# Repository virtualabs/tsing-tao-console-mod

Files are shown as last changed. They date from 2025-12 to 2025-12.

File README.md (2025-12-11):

# Tsing Tao v1 - a cheap ESP32 mod for a cheap handheld

Tsing Tao is a set of three tiny printed circuit boards that can turn any cheap
Chinese handheld gaming console (sold as Game Boy like console with 400+ NES
games) into a full-featured retro emulator able to run GameBoy, Game Gear, NES,
and Master System ROMs.

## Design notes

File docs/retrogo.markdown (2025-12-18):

---
layout: default
title: Flashing RetroGo
nav_order: 4
---

Flashing Retro-Go
=================

Once the mod installed in the handeld console, it is time to flash the ESP32 system
with a compatible Retro-Go version that has been specifically developed for this mod.
Retro-Go is a wonderful ESP32 retro-gaming platform using various emulators to run
old games on emulated consoles. It is easy to deploy and the [project website](https://github.com/ducalex/retro-go)
does explain how to manage games on the device's SD card and much more. 

Download our custom Retro-Go image
----------------------------------

We provide a prebuilt image for this TsingTao mod that can be downloaded from [our release page](https://github.com/virtualabs/retro-go/releases/download/tsingtao-v1.0/tsingtao-retrogo-v1.img).
This image has been specifically built for this mod and features some hardcoded configuration
and custom drivers to correctly interface with the console screen and our dedicated daughter boards.

You can also follow [the build instructions](https://github.com/virtualabs/retro-go/blob/master/BUILDING.md)
to compile it from source, and flash the generated image into the mod system.

Flash your ESP32
----------------

*Important: do not insert any micro SD card in the console's SD card holder !*

First, you need to install `esptool` on your system, as it is required to successfully flash
the TsingTao Retro-Go image. It should be available in most Linux distributions as a standard
package, if not you can install it by following [Espressif's setup guide](https://docs.espressif.com/projects/esptool/en/latest/esp32/).

Then, connect your modded console to your computer using a USB cable. Make sure the console is powered
on (power switch facing `ON`), and issue the following command (replace ``tsingtao-retrogo-v*.img`` with the
filename of the image downloaded in the previous step):

```shell
$ esptool.py write_flash --flash_size detect 0x0 tsingtao-retrogo-v*.img
```

This operation can take minutes to complete. Once done, switch off the console.

First boot
----------

Format your micro SD card in FAT32 and insert it into the micro SD card holder. Then switch on
the console, it will fill the micro SD card with the required folders for ROMS and themes at
first boot.

Switch off the console again, eject the micro SD card and copy ROM files to the corresponding
folders and insert it again into the handeld. Switch it on, and you should see your games in
the list of games of the console they were designed to run on.

Enjoy !

Frequently Asked Questions
==========================

TsingTao is not detected when connected to my computer, did I do anything wrong ?
---------------------------------------------------------------------------------

First, make sure the USB cable used to connect the console to your computer is not a charge-only
USB cable. Then, check the power switch has correctly been placed when reassembling the console:
it could be misplaced and tit won't switch the console on. If any of this worked, check your
solder job and make sure the mod's `DM` and `DP` pads are correctly connected to the type A USB
plug.

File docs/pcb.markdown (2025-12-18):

---
layout: default
title: PCB Assembly
nav_order: 2
---

PCB Assembly
============

{:refdef: style="text-align: center;"}
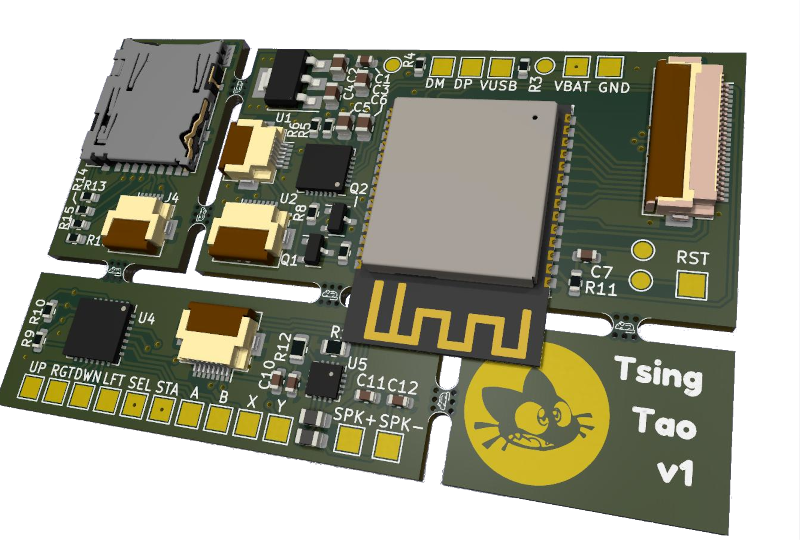
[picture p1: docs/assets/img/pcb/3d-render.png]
3D render of the mod's PCB

{: refdef}

Gerber export
-------------

This mod's PCB can be poroduced by many Chinese low-cost PCB manufacturers like [JLCPCB](https://jlcpcb.com) or
[PCBWay](https://pcbway.com) using [this Gerber file (ZIP)](https://raw.githubusercontent.com/virtualabs/tsing-tao-console-mod/refs/heads/main/gerber/tsing-tao-mod-v1.gerber.zip).

Bill of Materials
-----------------

| Designator |  Value |  Footprint | Description |  Quantity |
|---|---|---|---|---|
| R12 | 1 M | 0805 | Resistor 250mW | 1 |
| R4 | 47.5 k | 0603 | Resistor 250mW | 1 |
| R3 | 22.1k | 0603 | Resistor 250mW | 1 |
| R11, R6, R7, R8 | 10 k | 0603 | Resistor 250mW | 4 |
| R5 | 1 k | 0603 | Resistor 250mW | 1 |
| R13, R14, R15, R16 | 4.7 k | 0603 | Resistor 250mW | 4 |
| C9 | 10 uF | 0603 | Capacitor | 1 |
| C2, C3, C6 | 10 uF | 0805 | Capacitor | 3 |
| C5 | 1 uF | 0805 | Capacitor | 1 |
| C1, C7, C10 | 100 nF | 0603 | Capacitor | 2 |
| C11, C12 | 220 pF | 0603 | Capacitor | 2 |
| C4 | 100nF | 0805 | Capacitor | 1 |
| FB1, FB2 | - | 0805 | Ferrite bead | 2 |
| Q1, Q2 | MMS8050 | SOT-23-3 | NPN transistor | 2 |
| J1 | FH12-24S-0.5SH-1MP  | - | FPC connector, 24p, pitch 0.5mm| 1 |
| J2 | DM3AT-SF-PEJM5 | - | micro SD Card holder | 1 |
| J3, J4 | FH12-6S-0.5SH-1MP | - | FPC connector, 6p, pitch 0.5mm | 2 |
| J5, J6 | FH12-8S-0.5SH-1MP | - | FPC connector, 8p, pitch 0.5mm | 2 |
| U1 | AMS1117-3.3 | SOT-223-3 | LDO 3.3V 1A | 1 |
| U2 | CP2102N | QFN-28-1EP_5x5mm | USB-to-UART bridge | 1 |
| U3 | ESP32-S3-WROOM-1 | - | ESP32 S3, Espressif | 1 |
| U4 | MCP23017_ML | QFN-28-1EP_6x6mm | I2C GPIO expander, 16 IO | 1 |
| U5 | MAX98357A | TQFN-16-1EP_3x3mm| I2S Audio DAC + Amp. | 1 |

PCB soldering
-------------

*Note:* the pictures showed in this section have been taken during the soldering of the second
prototype PCB. This previous version did not have mousebites and each section had to be soldered
separately. The PCB version presented here does have mousebites and can be soldered in a single piece.

To solder this printed circuit board, use the classic procedure:
- apply solder paste using a stencil or by hand
- pick and place components manually (mind their orientation, especially for ICs)
- use a hot plate soldering device to heat up the PCB until the solder paste melt, make sure all components are soldered and remove from the hot plate.

{:refdef: style="text-align: center;"}
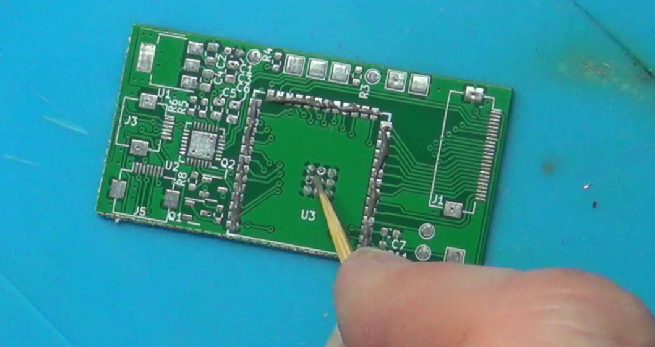
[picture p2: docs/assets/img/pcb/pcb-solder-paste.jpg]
Solder paste placed on pads

{: refdef}

{:refdef: style="text-align: center;"}
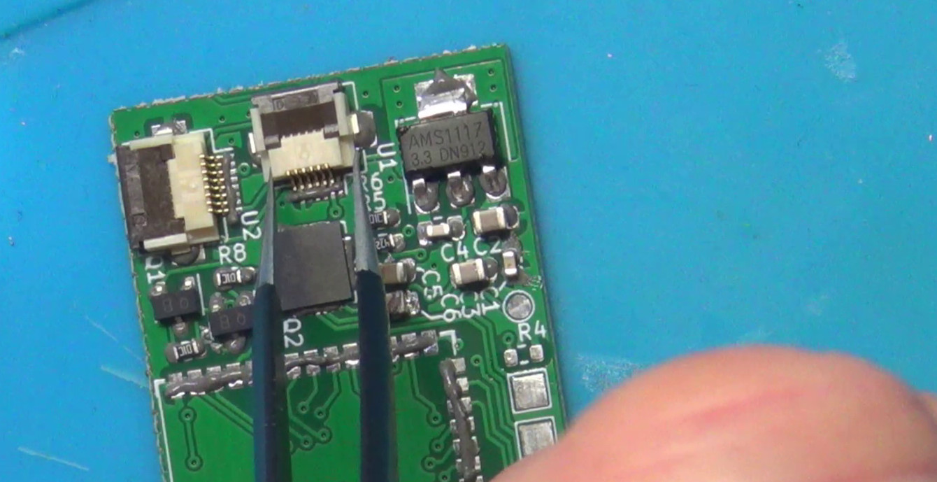
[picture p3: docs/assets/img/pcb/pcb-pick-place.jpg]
Placing components on PCB

{: refdef}

{:refdef: style="text-align: center;"}
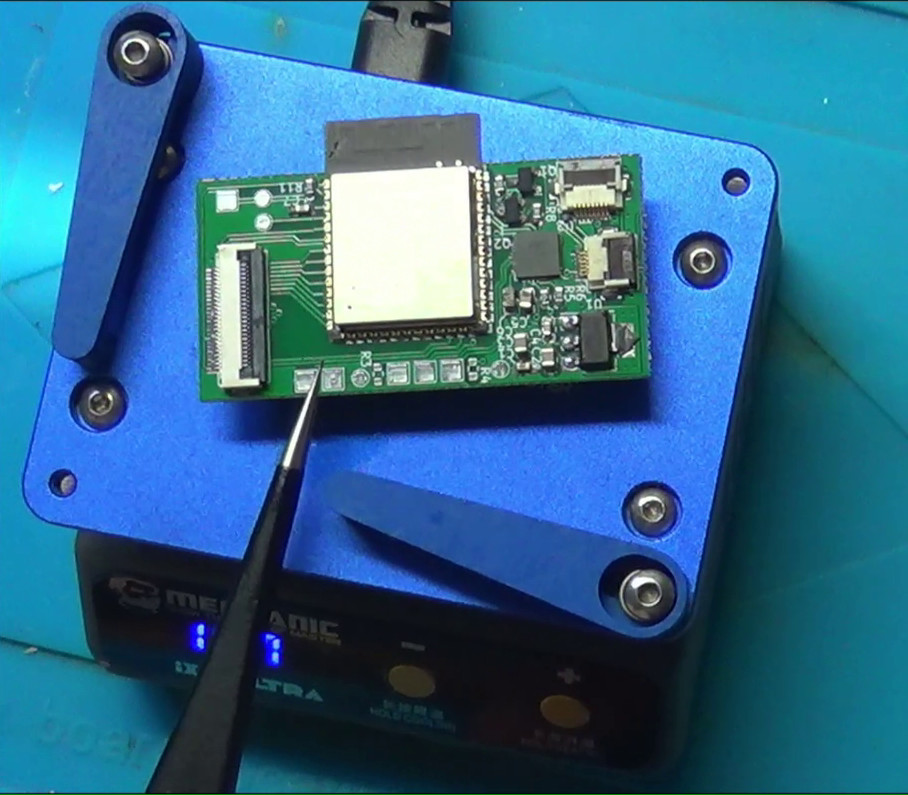
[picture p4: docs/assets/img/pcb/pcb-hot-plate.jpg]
Reflow with a Mechanic hotplate

{: refdef}

{:refdef: style="text-align: center;"}
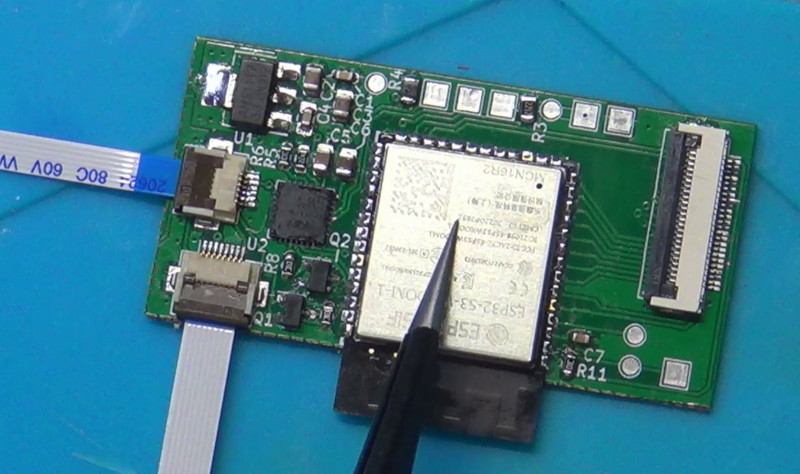
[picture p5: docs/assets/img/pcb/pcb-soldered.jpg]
Soldered PCB

{: refdef}

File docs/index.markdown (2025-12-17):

---
layout: default
nav_order: 1
---

Introducing TsingTao
====================

TsingTao is a custom mod for those cheap Chinese consoles you can find on the Internet,
like the one below:

{:refdef:  style="text-align: center;"}
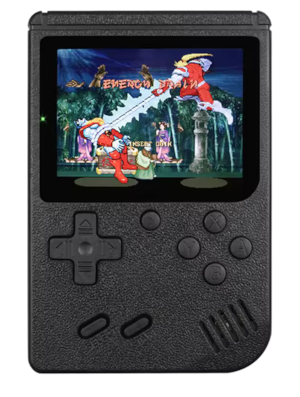
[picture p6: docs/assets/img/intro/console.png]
Cheap handeld console from AliExpress

{: refdef}

The goal of this mod is to reuse the following components of this console:
- console shell and lid
- 1020 mAh battery
- power and battery management circuit
- TFT screen
- speaker

This mod runs with a [Retro-Go](https://github.com/ducalex/retro-go) based firmware on a ESP32-based system and is able to
correctly emulate ROMS for the following consoles:
- Nintendo NES
- Nintendo GameBoy & GameBoy Color
- SEGA Game Gear
- SEGA Master System
- PC Engine
- Atari Lynx

Required hardware
-----------------

- 1 cheap Chinese handeld console, [like this one](https://fr.aliexpress.com/item/1005005986614521.html)
- 1 TsingTao mod kit (PCB + components)
- a soldering iron with enough solder (.5mm diameter recommended)
- desoldering wick
- soldering flux
- a pair of tweezers
- AWG30 monocore wire (or similar)
- .15mil enameled copper wire (very thin silicon-coated monocore wire could also work)
- tiny hot plate for PCB assembly, [like this one](https://fr.aliexpress.com/item/1005008702721210.html)
- a dremel equiped with a cutting disc, or equivalent

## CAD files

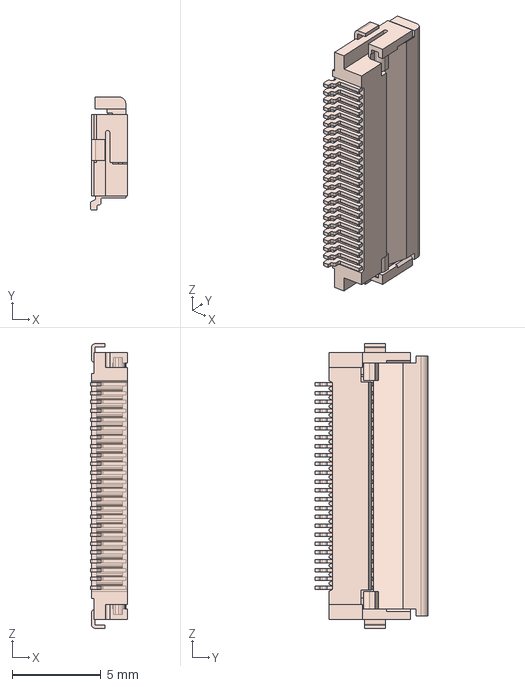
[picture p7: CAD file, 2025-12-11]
pcb/FH12-24S-0.5SH(55)--3DModel-STEP-1.STEP
2.10 x 6.40 x 16.1 mm

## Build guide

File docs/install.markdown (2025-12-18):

---
layout: default
title: Installation
nav_order: 3
---

Installation
============

This section details the installation of the *TsingTao* mod inside the console.

Disassembling the handeld
-------------------------

First, remove the console lid and battery located on the rear side of the device. Then remove the
six screws holding the the two halves of the console's main shell:

{:refdef: style="text-align: center;"}
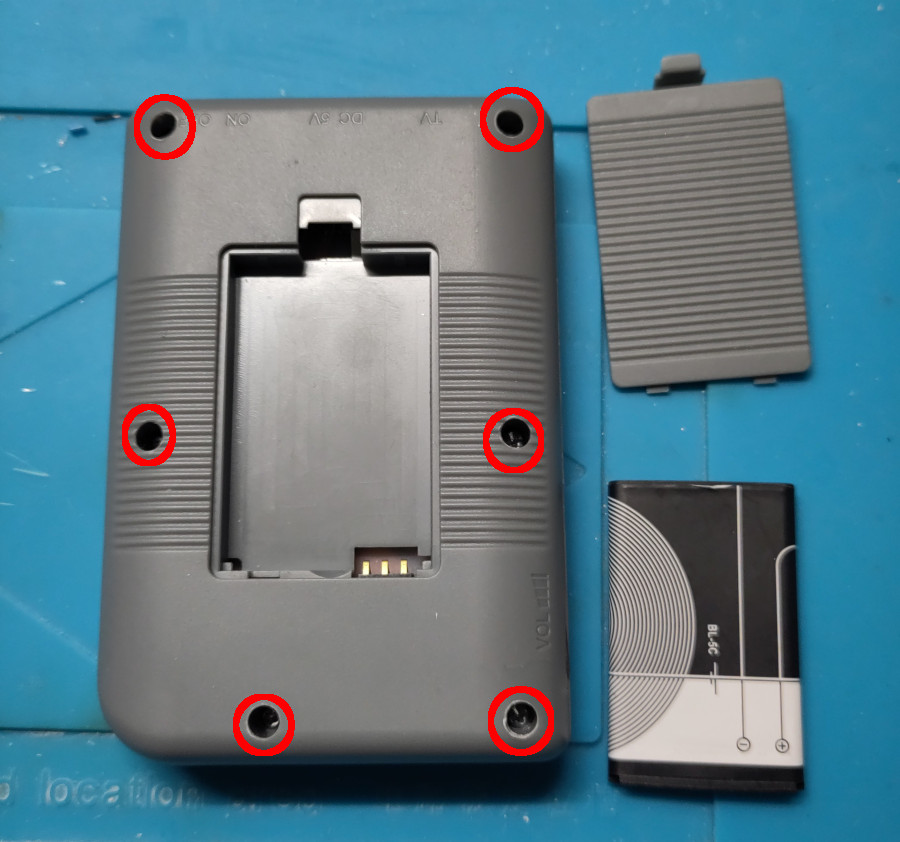
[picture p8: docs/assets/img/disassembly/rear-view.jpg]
Location of the six screws

{: refdef}

Once opened, extract the PCB from the device and put the two halves of the main shell aside.
This PCB should look like the one below (note that there are a lot of variants for these handeld
consoles, it is very likely that your PCB differs from the one showed here):

{:refdef: style="text-align: center;"}
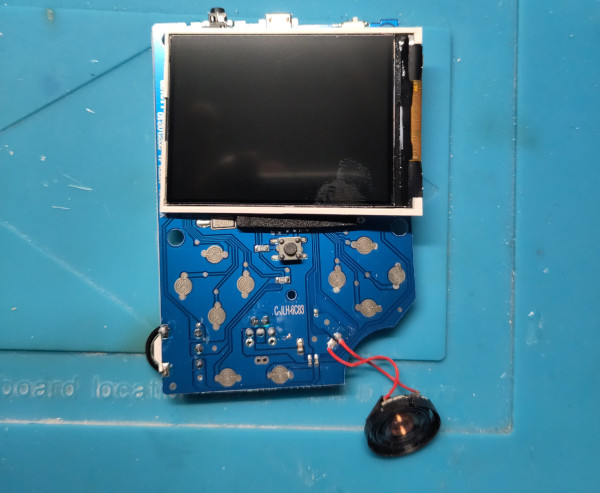
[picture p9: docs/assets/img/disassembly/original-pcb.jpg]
Original PCB extracted from handeld

{: refdef}

Disconnect the screen from the PCB: gently lift the socket's lip with a plastic tool (avoid using a blade
or a flat screwdriver as it may damage the screen's ribbon) and caregully remove the ribbon from the socket.
Keep this screen far from the workbench to avoid any scratch or damage (required in the final build).

Desolder the speaker using a soldering iron and a pair of tweezers. Keep it in a secure place to avoid any
damage, we will need it later.

Prepping the board
------------------

We need to get rid of the original ASIC and flash memory to make some space for our mod:
- desolder the main Flash chip by using a soldering iron or a hot plate
  (flash chip aspect may differ from the one showed below, depending on the version and variant)
- with a dremel, cut the PCB following the lines showed below

{:refdef: style="text-align: center;"}
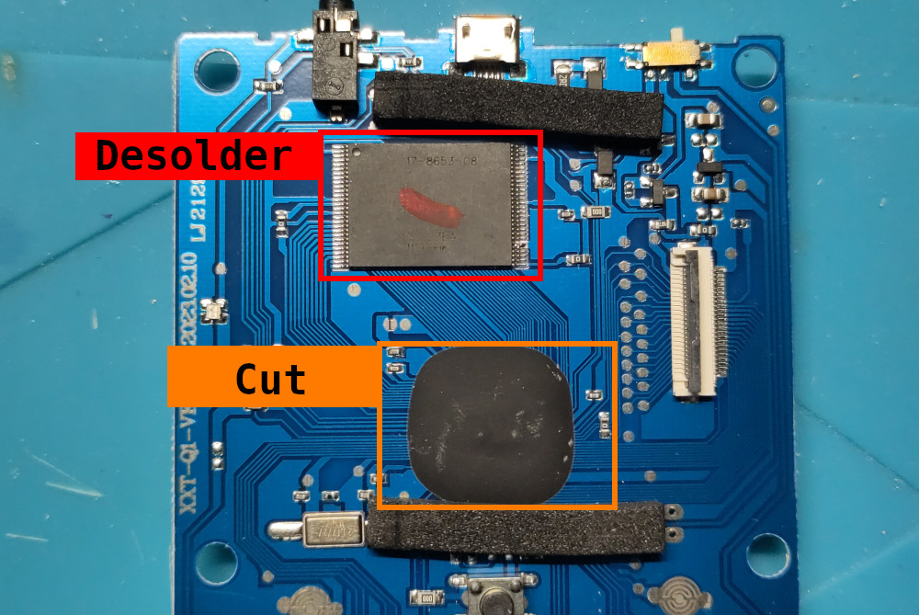
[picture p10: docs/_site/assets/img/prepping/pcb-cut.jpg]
Desolder main Flash and cut out ASIC

{: refdef}

Please desolder and cut wisely, avoid touching any other critical components like those related to power
supply, USB port or screen connector. Cut as close as possible from the ASIC (the big black epoxy blob)
and try to keep the reset button intact (the tactile switch placed just below the ASIC).

Installing the main PCB
-----------------------

Once the ASIC and Flash chip removed, place the main PCB of the *TsingTao* mod onto the original PCB in
a way the screen connector is placed close to its original location. Use some double-sided tape to stick
it to the original PCB before doing any soldering job.

{:refdef: style="text-align: center;"}
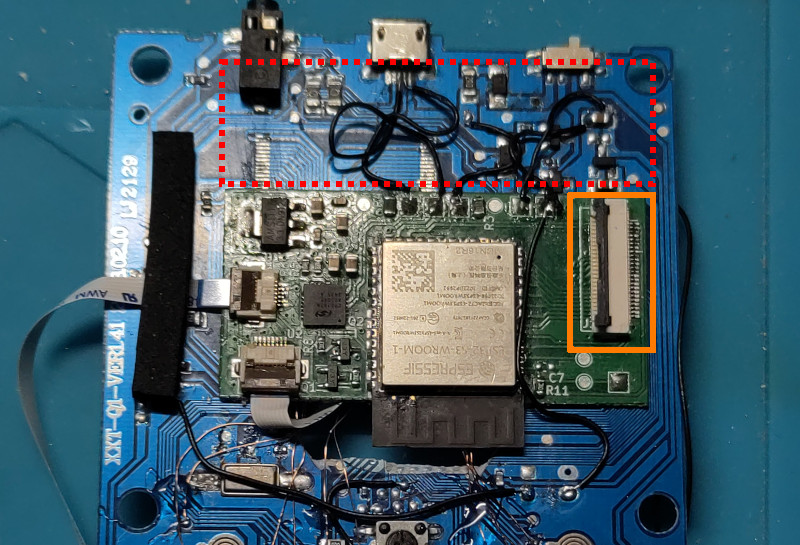
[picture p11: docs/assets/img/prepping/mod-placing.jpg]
Placing the mod onto the original PCB

{: refdef}

Avoid covering the area marked in red as it holds the power supply circuit and make sure the screen
connector aligns perfectly with the original screen connector location (marked in orange).

Soldering the main mod's PCB
----------------------------

Before soldering, make sure you have already identified the main power supply lines:
- `+5V` provided by the USB socket
- `Vbat` that corresponds to the battery voltage, usually wired to the device's power switch
- `Gnd` (basically tied to the original board's ground plane and USB socket's external case)

Cut the USB socket `D+` and `D-` tracks and solder two wires:
- one from the socket's `D+` pad to the mod's PCB `DP` pad
- one from the socket's `D-` pad to the mod's PCB `DM` pad

Then, solder the power supply wires:
- from the board's `+5V` taken from the USB socket to the mod's PCB `5V` pad
- from the board's `Vbat` power line to the mod's PCB `VBAT` pad
- from the board's `GND` to the mod's PCB `GND` pad

{:refdef: style="text-align: center;"}
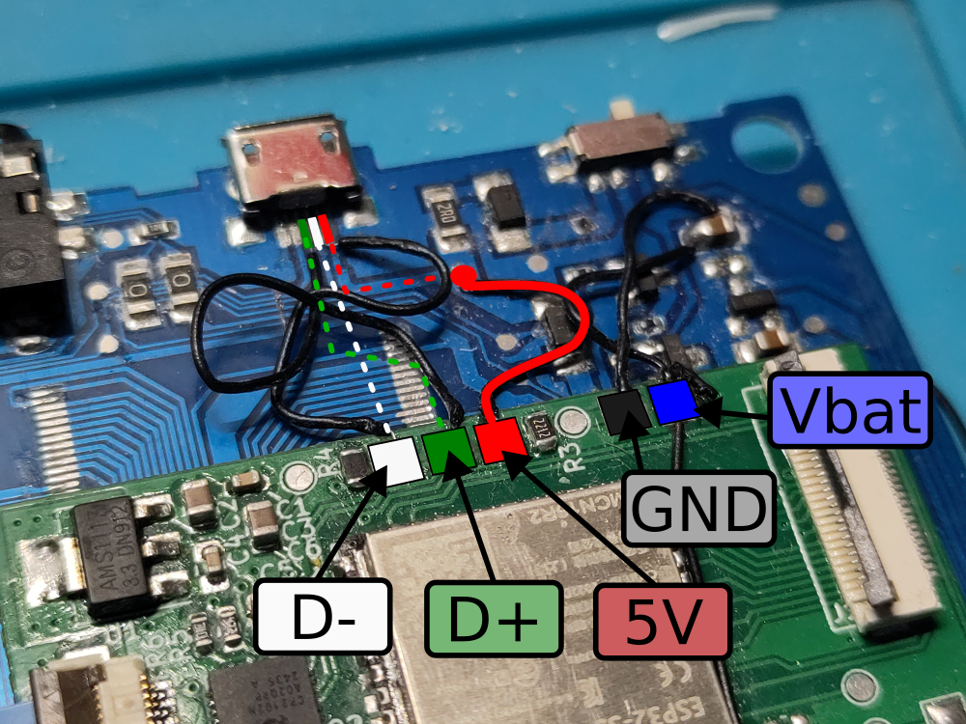
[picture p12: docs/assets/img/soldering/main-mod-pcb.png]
Main mod PCB soldering

{: refdef}

The mod's main PCB is now conencted to the device's USB port and power lines.
We can test it by connecting it to a host computer through a USB cable while
keeping its power switch set to *OFF*. A USB device should be shortly detected
and then disconnected as the ESP32 is keeping rebooting (since it has not already
been programmed).

Soldering the auxiliary PCB (handling buttons and sound)
--------------------------------------------------------

The mod's auxiliary PCB is in charge of probing the console's buttons and sending
audio to the external speaker. It should be placed on the back side of the handeld's
original PCB, placed under the USB connector. This auxialiary PCB is connected to
the mod's main PCB through a 8-pin flat ribbon.

We use small enameled wires to connect the buttons to this PCB, as shown below:

{:refdef: style="text-align: center;"}
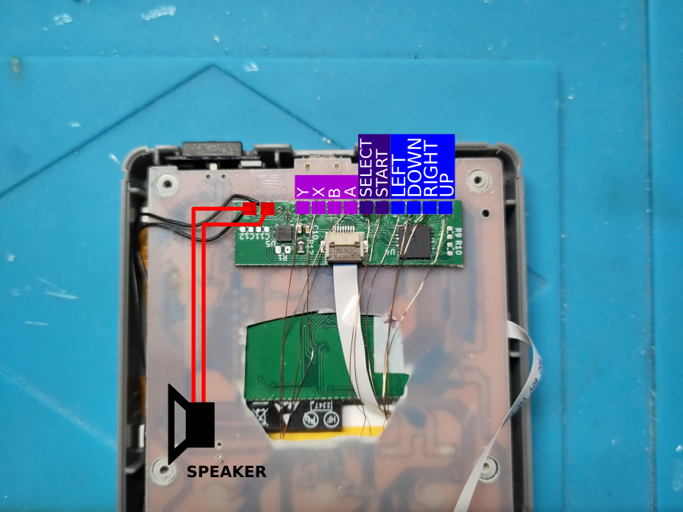
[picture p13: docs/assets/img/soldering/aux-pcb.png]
Aux mod PCB soldering

{: refdef}

{:refdef: style="text-align: center;"}
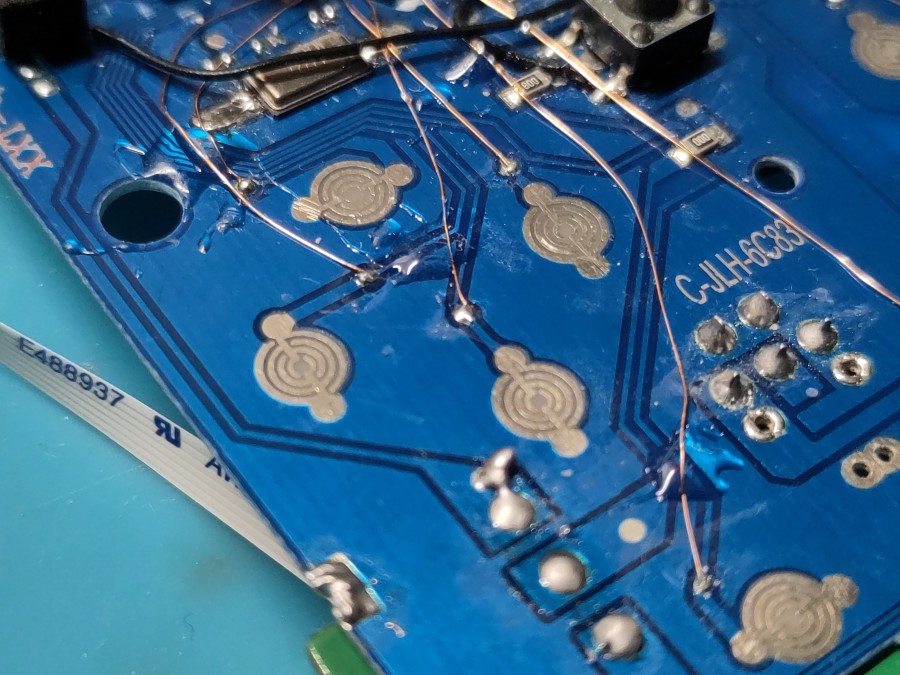
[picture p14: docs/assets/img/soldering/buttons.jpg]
Soldering buttons

{: refdef}

Installing the SD card holder
-----------------------------

Place and tape the SD card PCB module at the bottom of the original PCB's back side,
as showed below:

{:refdef: style="text-align: center;"}
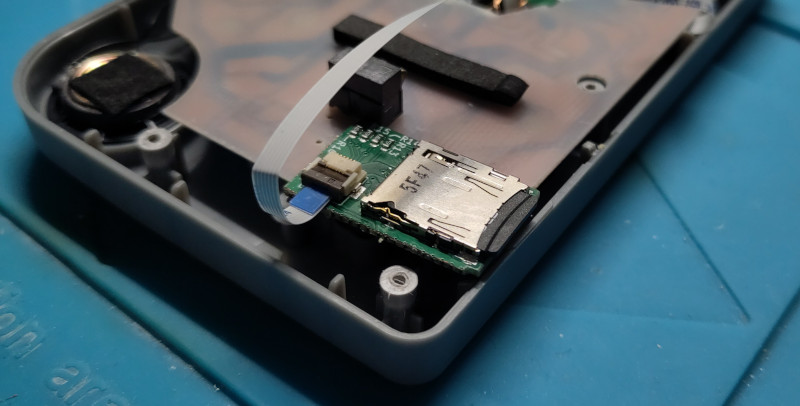
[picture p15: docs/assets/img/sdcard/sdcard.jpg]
SD card module taped

{: refdef}

Once placed and secured, connect it to the main mod's PCB using a 6-pin flex
ribbon. Cut the main shell's bottom half to make some room for the SD card
and allow easy access from the outside. The picture below shows how it was
done for our first prototype:

{:refdef: style="text-align: center;"}
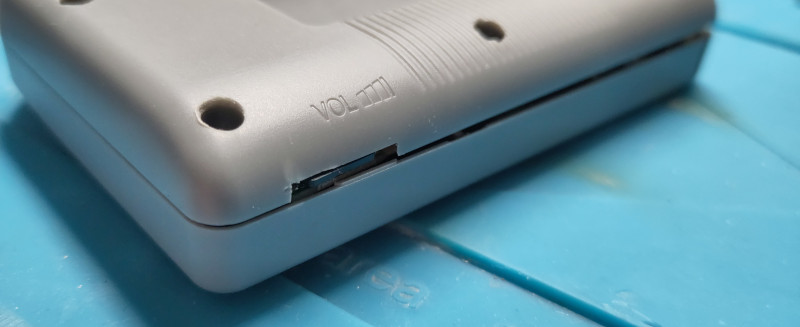
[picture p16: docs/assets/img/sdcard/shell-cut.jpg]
Cut shell

{: refdef}

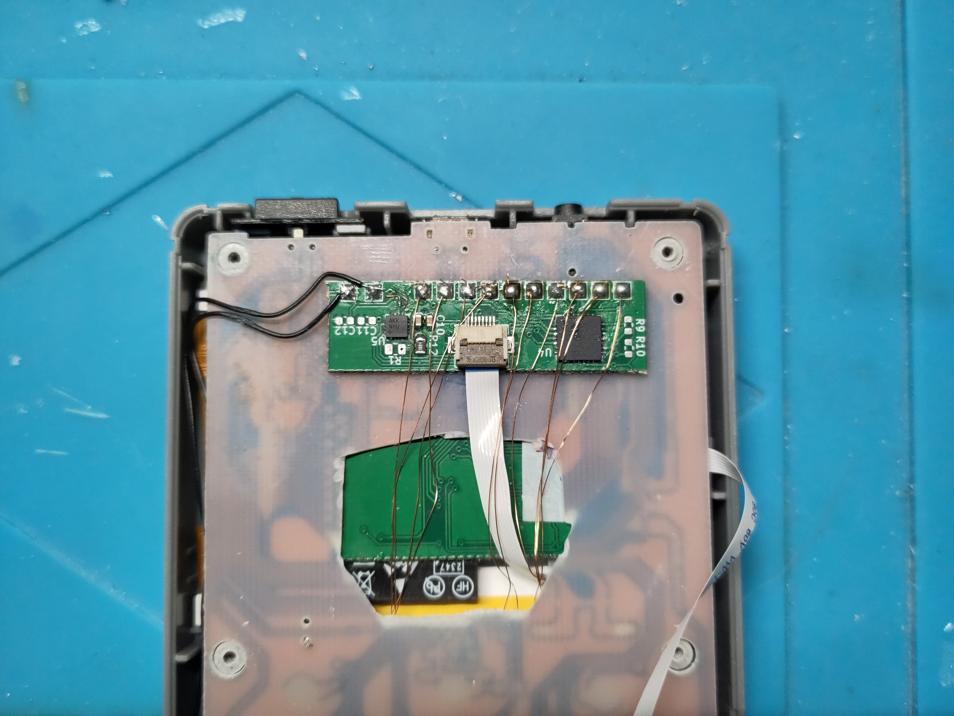
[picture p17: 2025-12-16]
docs/assets/img/soldering/auxiliary-pcb.jpg

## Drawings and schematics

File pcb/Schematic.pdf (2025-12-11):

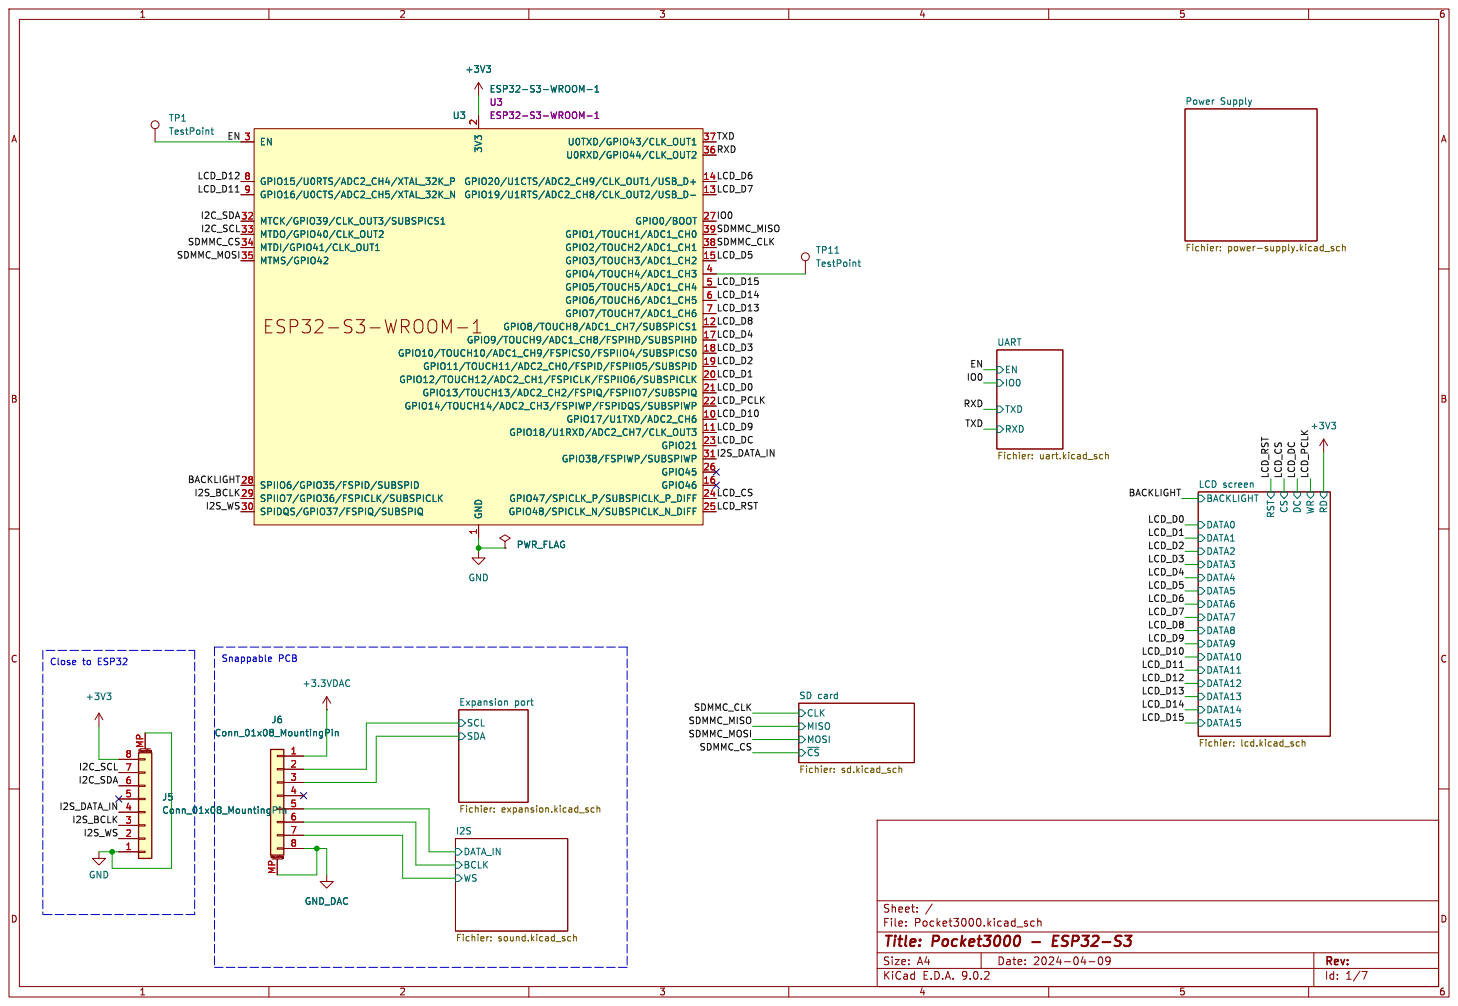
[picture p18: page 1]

1 U0TXD/GPIO43/CLK_OUT1 37 U0RXD/GPIO44/CLK_OUT2 36 GPIO20/U1CTS/ADC2_CH9/CLK_OUT1/USB_D+ 14 GPIO19/U1RTS/ADC2_CH8/CLK_OUT2/USB_D- 13 GPIO0/BOOT 27 GPIO1/TOUCH1/ADC1_CH0 39 GPIO2/TOUCH2/ADC1_CH1 38 GPIO3/TOUCH3/ADC1_CH2 15 GPIO4/TOUCH4/ADC1_CH3 4 GPIO5/TOUCH5/ADC1_CH4 5 GPIO6/TOUCH6/ADC1_CH5 6 GPIO7/TOUCH7/ADC1_CH6 7 GPIO8/TOUCH8/ADC1_CH7/SUBSPICS1 12 GPIO9/TOUCH9/ADC1_CH8/FSPIHD/SUBSPIHD 17 GPIO10/TOUCH10/ADC1_CH9/FSPICS0/FSPIIO4/SUBSPICS0 18 GPIO11/TOUCH11/ADC2_CH0/FSPID/FSPIIO5/SUBSPID 19 GPIO12/TOUCH12/ADC2_CH1/FSPICLK/FSPIIO6/SUBSPICLK 20 GPIO13/TOUCH13/ADC2_CH2/FSPIQ/FSPIIO7/SUBSPIQ 21 GPIO14/TOUCH14/ADC2_CH3/FSPIWP/FSPIDQS/SUBSPIWP 22 GPIO17/U1TXD/ADC2_CH6 10 GPIO18/U1RXD/ADC2_CH7/CLK_OUT3 11 GPIO21 23 GPIO38/FSPIWP/SUBSPIWP 31 GPIO45 26 GPIO46 16 GPIO47/SPICLK_P/SUBSPICLK_P_DIFF 24 GPIO48/SPICLK_N/SUBSPICLK_N_DIFF 25 U3 ESP32-S3-WROOM-1 U3ESP32-S3-WROOM-1

Power Supply Fichier: power-supply.kicad_sch

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

UART
LCD screen Fichier: lcd.kicad_sch

PWR_FLAG
Fichier: sound.kicad_sch SCL SDA

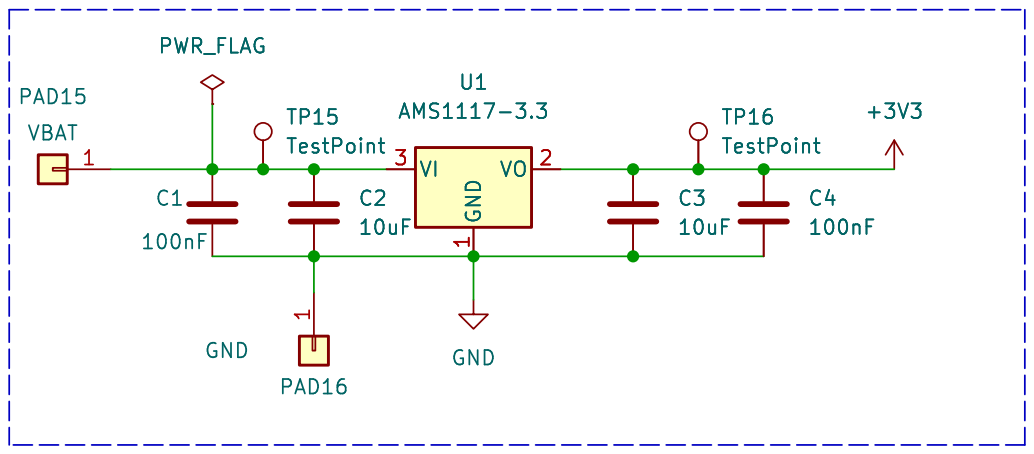
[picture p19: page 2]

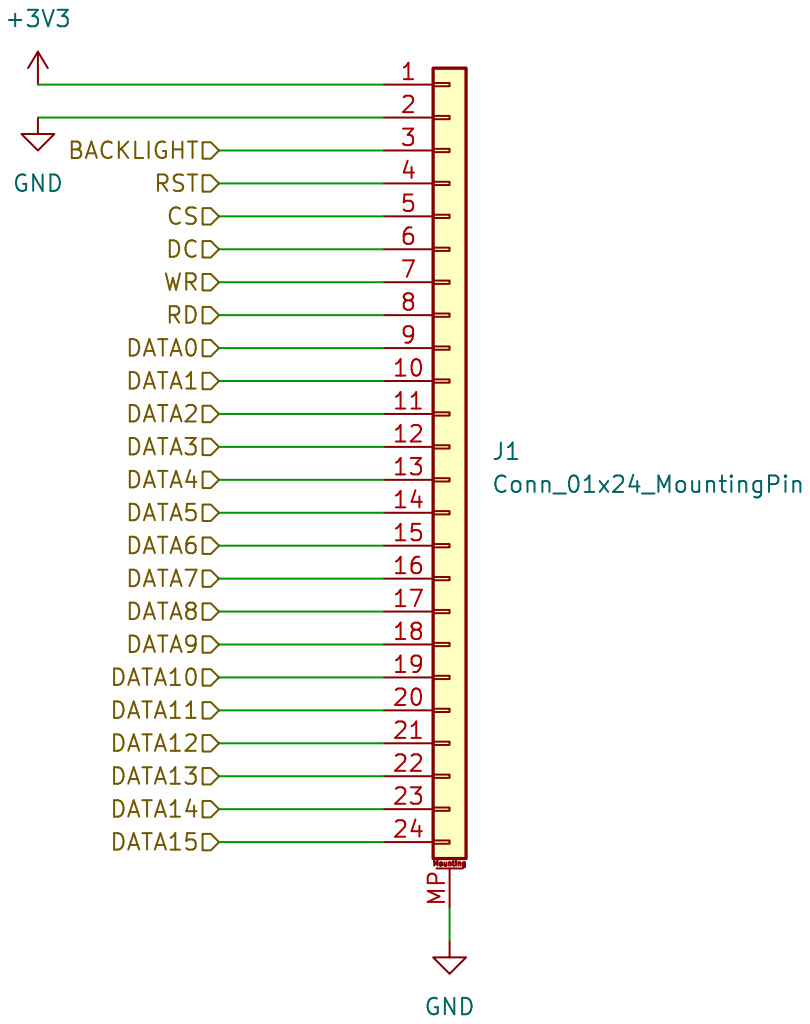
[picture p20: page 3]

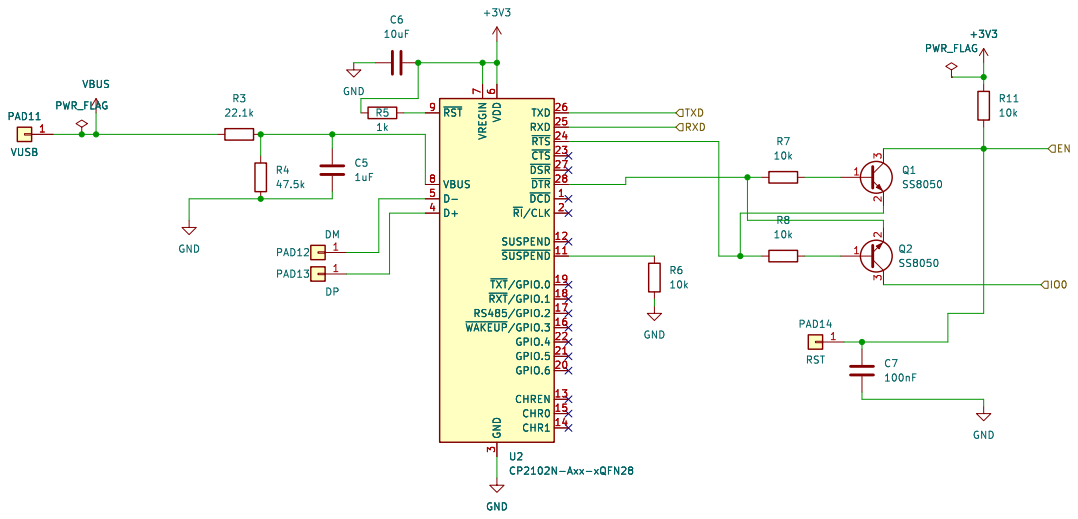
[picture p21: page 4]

3 TXD 26 RXD 25 ~{RTS} 24 ~{CTS} 23 ~{DSR} 27 ~{DTR} 28 ~{DCD}1 ~{RI}/CLK2 SUSPEND 12 ~{SUSPEND}11 ~{TXT}/GPIO.019 ~{RXT}/GPIO.118 RS485/GPIO.2 17 ~{WAKEUP}/GPIO.316 GPIO.4 22 GPIO.5 21 GPIO.6 20 CHREN 13 CHR0 15 CHR1 14 U2 CP2102N-Axx-xQFN28 GND GND

3 TXD 26 RXD 25 ~{RTS} 24 ~{CTS} 23 ~{DSR} 27 ~{DTR} 28 ~{DCD}1 ~{RI}/CLK2 SUSPEND 12 ~{SUSPEND}11 ~{TXT}/GPIO.019 ~{RXT}/GPIO.118 RS485/GPIO.2 17 ~{WAKEUP}/GPIO.316 GPIO.4 22 GPIO.5 21 GPIO.6 20 CHREN 13 CHR0 15 CHR1 14 GND

Id: 4/7 Title: File: uart.kicad_sch Sheet: /UART/

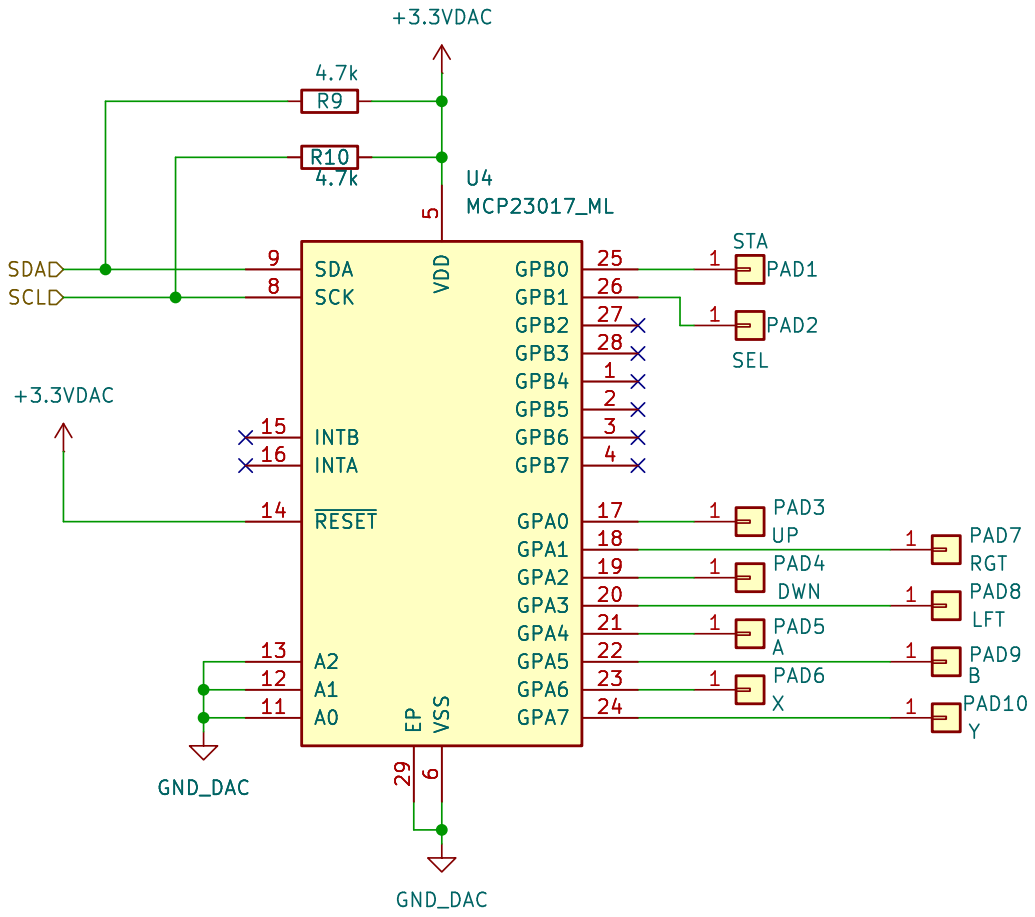
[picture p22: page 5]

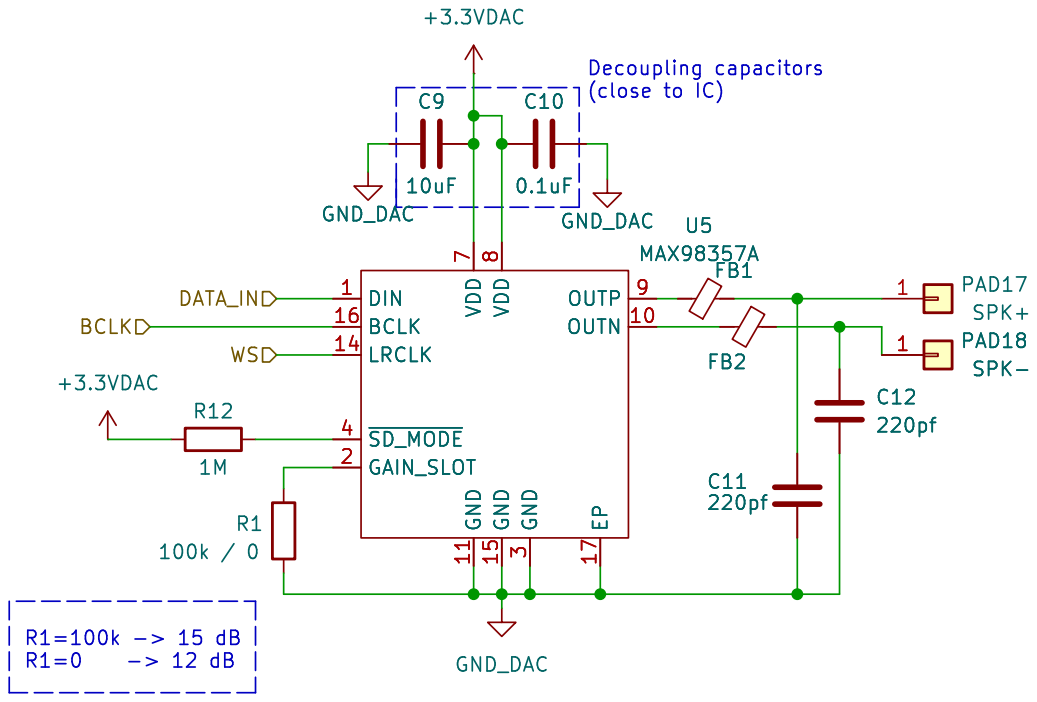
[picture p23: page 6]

Id: 6/7 Title: File: sound.kicad_sch Sheet: /I2S/

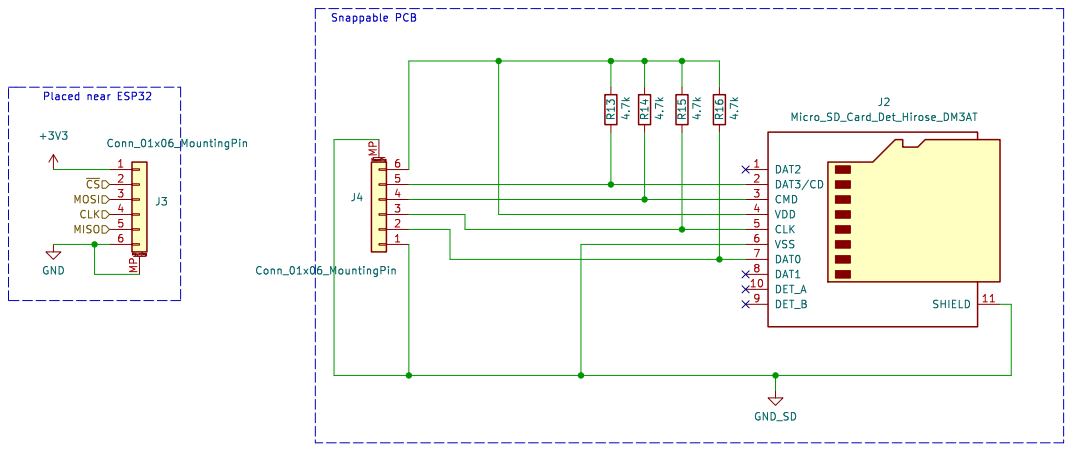
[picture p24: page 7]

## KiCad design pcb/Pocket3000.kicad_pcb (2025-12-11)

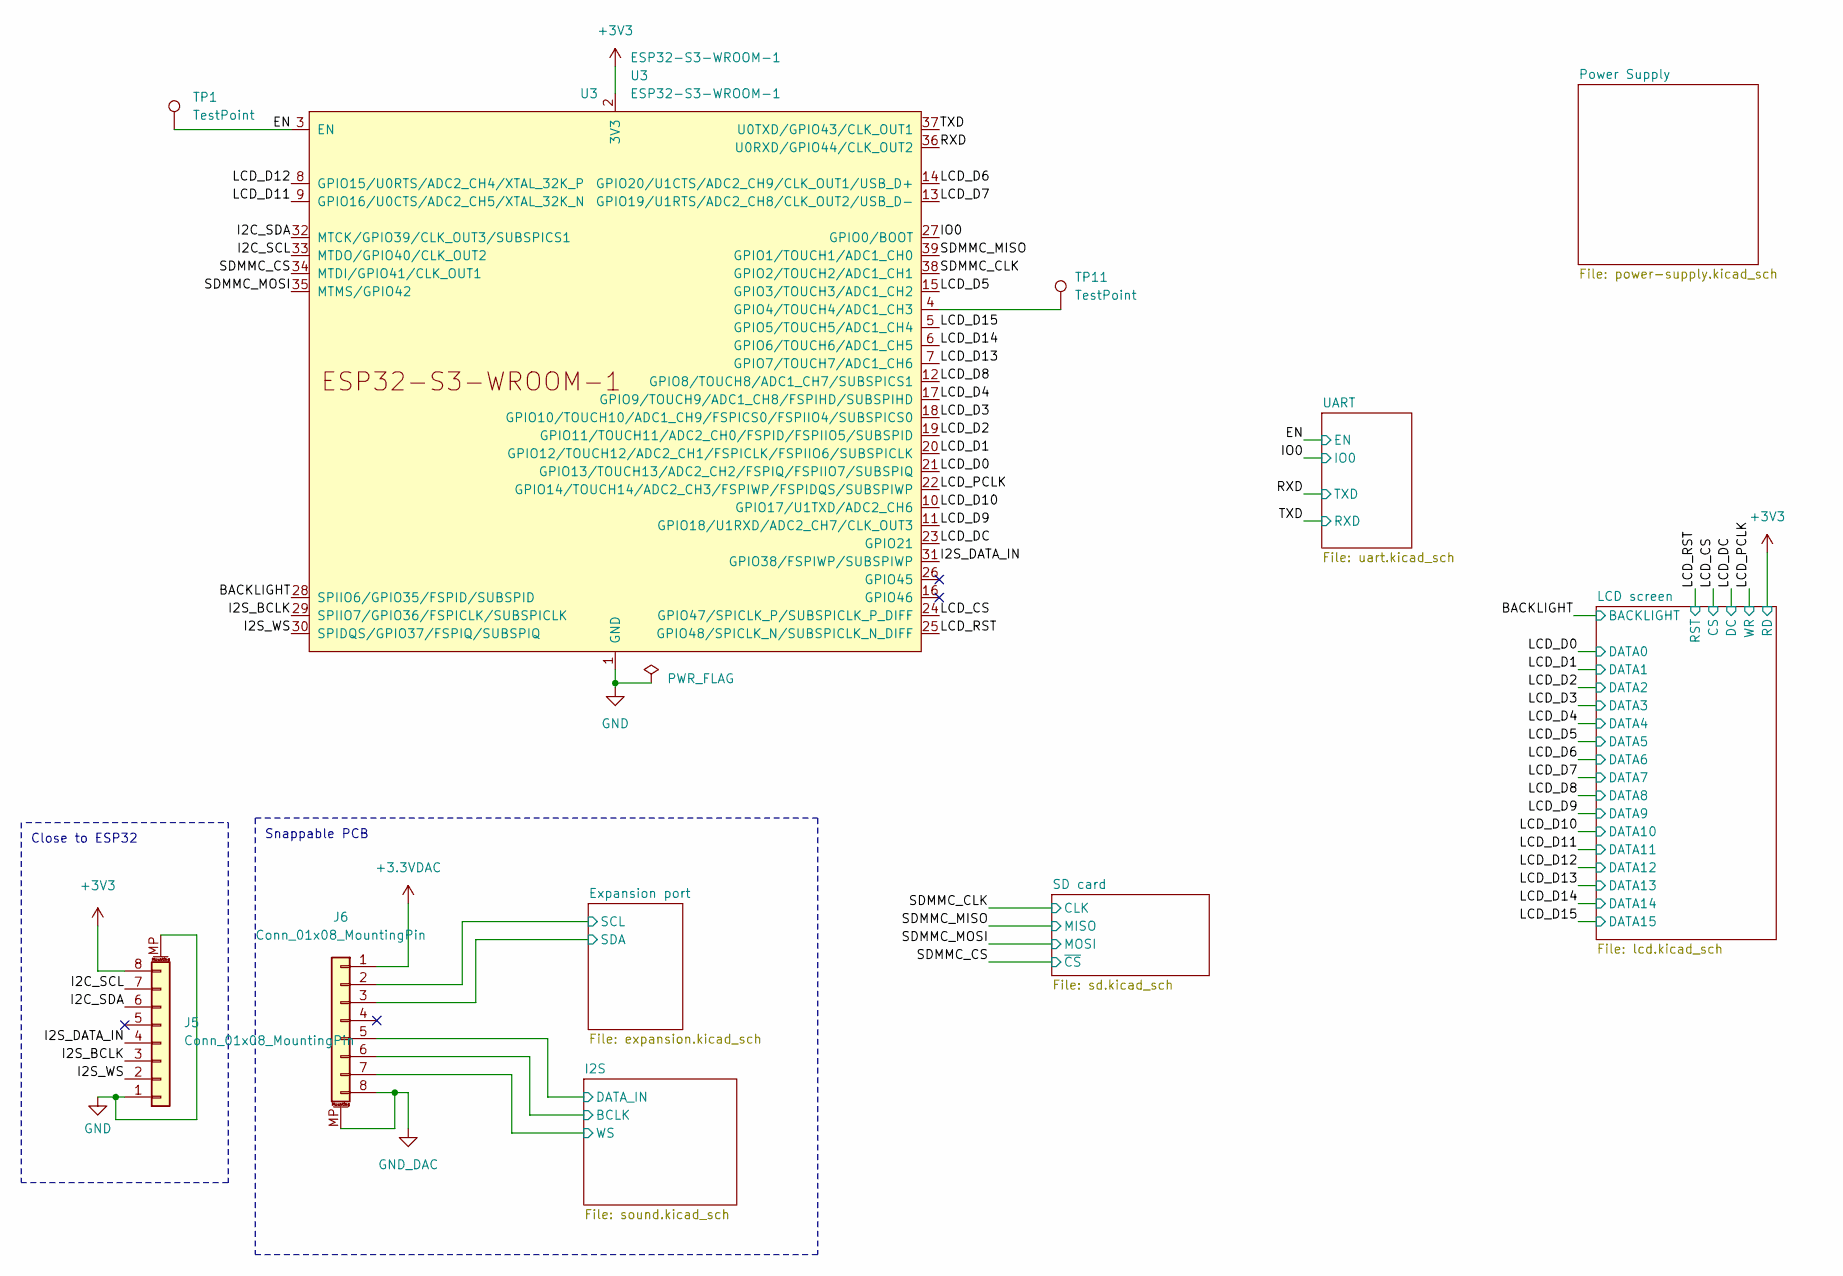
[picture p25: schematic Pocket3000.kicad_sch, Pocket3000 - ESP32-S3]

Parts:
J5, J6: Conn_01x08_MountingPin; Hirose_FH12-8S-0.5SH_1x08-1MP_P0.50mm_Horizontal
TP1, TP11: TestPoint; TestPoint_Pad_D1.5mm
U3: ESP32-S3-WROOM-1; ESP32-S3-WROOM-1U

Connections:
+3.3VDAC: J6.1; also elsewhere on the board
+3V3: J5.8, U3.2 (3V3); also elsewhere on the board
/BACKLIGHT: U3.28 (SPIIO6/GPIO35/FSPID/SUBSPID); also elsewhere on the board
/EN: TP1.1, U3.3 (EN); also elsewhere on the board
/Expansion port/SCL: J6.2; also elsewhere on the board
/Expansion port/SDA: J6.3; also elsewhere on the board
/I2C_SCL: J5.7, U3.33 (MTDO/GPIO40/CLK_OUT2)
/I2C_SDA: J5.6, U3.32 (MTCK/GPIO39/CLK_OUT3/SUBSPICS1)
/I2S/BCLK: J6.6; also elsewhere on the board
/I2S/DATA_IN: J6.5; also elsewhere on the board
/I2S/WS: J6.7; also elsewhere on the board
/I2S_BCLK: J5.3, U3.29 (SPIIO7/GPIO36/FSPICLK/SUBSPICLK)
/I2S_DATA_IN: J5.4, U3.31 (GPIO38/FSPIWP/SUBSPIWP)
/I2S_WS: J5.2, U3.30 (SPIDQS/GPIO37/FSPIQ/SUBSPIQ)
/IO0: U3.27 (GPIO0/BOOT); also elsewhere on the board
/LCD_CS: U3.24 (GPIO47/SPICLK_P/SUBSPICLK_P_DIFF); also elsewhere on the board
/LCD_D0: U3.21 (GPIO13/TOUCH13/ADC2_CH2/FSPIQ/FSPIIO7/S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); also elsewhere on the board
/LCD_D1: U3.20 (GPIO12/TOUCH12/ADC2_CH1/FSPICLK/FSPIIO6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); also elsewhere on the board
/LCD_D2: U3.19 (GPIO11/TOUCH11/ADC2_CH0/FSPID/FSPIIO5/S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); also elsewhere on the board
/LCD_D3: U3.18 (GPIO10/TOUCH10/ADC1_CH9/FSPICS0/FSPIIO4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); also elsewhere on the board
/LCD_D4: U3.17 (GPIO9/TOUCH9/ADC1_CH8/FSPIHD/SUBSPIHD); also elsewhere on the board
/LCD_D5: U3.15 (GPIO3/TOUCH3/ADC1_CH2); also elsewhere on the board
/LCD_D6: U3.14 (GPIO20/U1CTS/ADC2_CH9/CLK_OUT1/USB_D+); also elsewhere on the board
/LCD_D7: U3.13 (GPIO19/U1RTS/ADC2_CH8/CLK_OUT2/USB_D-); also elsewhere on the board
/LCD_D8: U3.12 (GPIO8/TOUCH8/ADC1_CH7/SUBSPICS1); also elsewhere on the board
/LCD_D9: U3.11 (GPIO18/U1RXD/ADC2_CH7/CLK_OUT3); also elsewhere on the board
/LCD_D10: U3.10 (GPIO17/U1TXD/ADC2_CH6); also elsewhere on the board
/LCD_D11: U3.9 (GPIO16/U0CTS/ADC2_CH5/XTAL_32K_N); also elsewhere on the board
/LCD_D12: U3.8 (GPIO15/U0RTS/ADC2_CH4/XTAL_32K_P); also elsewhere on the board
/LCD_D13: U3.7 (GPIO7/TOUCH7/ADC1_CH6); also elsewhere on the board
/LCD_D14: U3.6 (GPIO6/TOUCH6/ADC1_CH5); also elsewhere on the board
/LCD_D15: U3.5 (GPIO5/TOUCH5/ADC1_CH4); also elsewhere on the board
/LCD_DC: U3.23 (GPIO21); also elsewhere on the board
/LCD_PCLK: U3.22 (GPIO14/TOUCH14/ADC2_CH3/FSPIWP/FSPIDQS/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); also elsewhere on the board
/LCD_RST: U3.25 (GPIO48/SPICLK_N/SUBSPICLK_N_DIFF); also elsewhere on the board
/RXD: U3.36 (U0RXD/GPIO44/CLK_OUT2); also elsewhere on the board
/SDMMC_CLK: U3.38 (GPIO2/TOUCH2/ADC1_CH1); also elsewhere on the board
/SDMMC_CS: U3.34 (MTDI/GPIO41/CLK_OUT1); also elsewhere on the board
/SDMMC_MISO: U3.39 (GPIO1/TOUCH1/ADC1_CH0); also elsewhere on the board
/SDMMC_MOSI: U3.35 (MTMS/GPIO42); also elsewhere on the board
/TXD: U3.37 (U0TXD/GPIO43/CLK_OUT1); also elsewhere on the board
GND: J5.1, J5.MP (MountPin), U3.1 (GND), U3.40 (GND), U3.41 (GND); also elsewhere on the board
GND_DAC: J6.8, J6.MP (MountPin); also elsewhere on the board
unnamed: TP11.1, U3.4 (GPIO4/TOUCH4/ADC1_CH3)

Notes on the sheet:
Snappable PCB
Close to ESP32

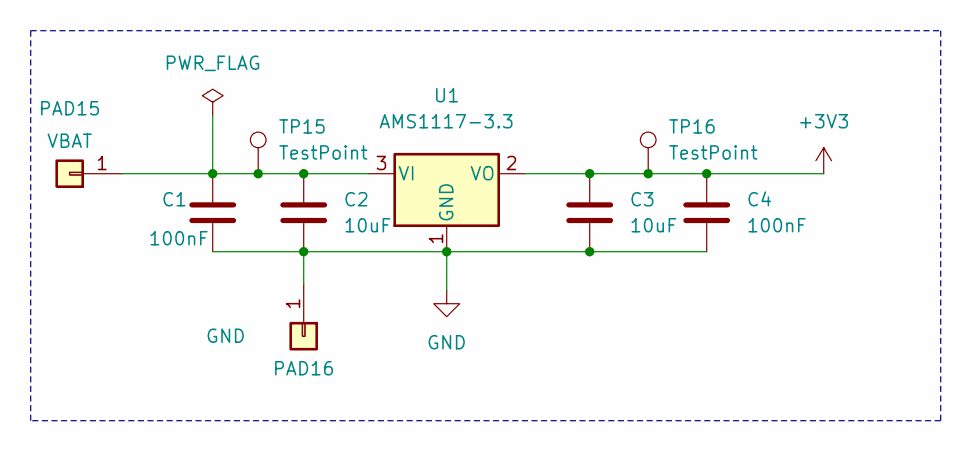
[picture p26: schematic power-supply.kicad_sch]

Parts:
C1: 100nF; C_0603_1608Metric
C2, C3: 10uF; C_0805_2012Metric
C4: 100nF; C_0805_2012Metric
PAD15: VBAT; TestPoint_Pad_2.0x2.0mm
PAD16: GND; TestPoint_Pad_2.0x2.0mm
TP15, TP16: TestPoint; TestPoint_Pad_D1.5mm
U1: AMS1117-3.3; SOT-223-3_TabPin2

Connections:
+3V3: C3.1, C4.1, TP16.1, U1.2 (VO); also elsewhere on the board
GND: C1.2, C2.2, C3.2, C4.2, PAD16.1, U1.1 (GND); also elsewhere on the board
unnamed: C1.1, C2.1, PAD15.1, TP15.1, U1.3 (VI)

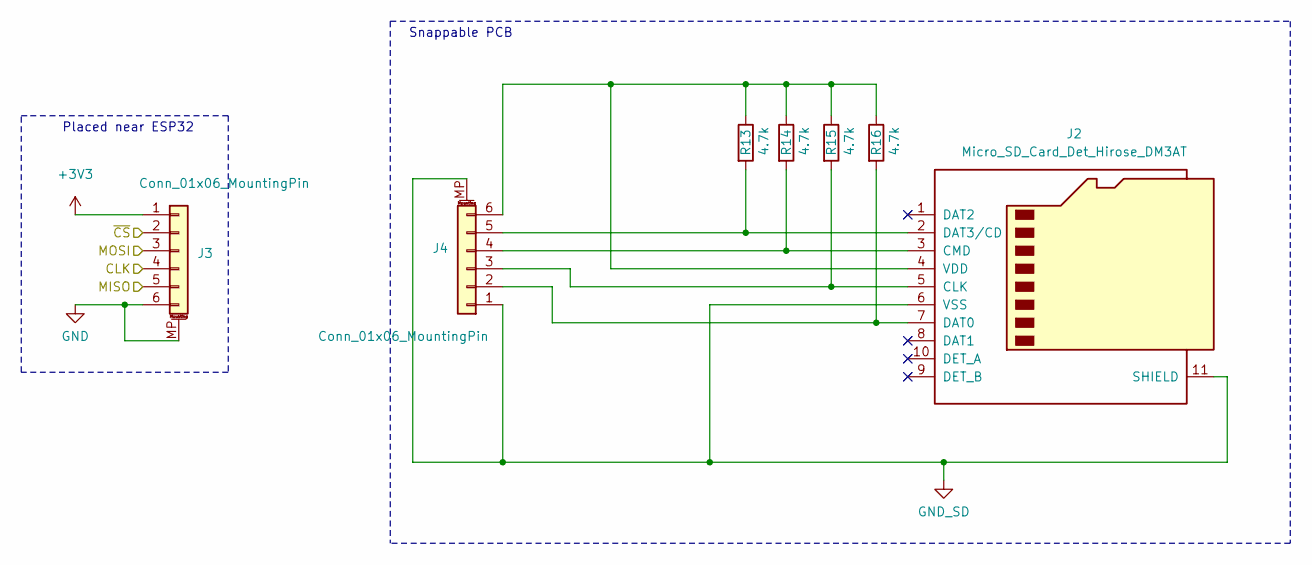
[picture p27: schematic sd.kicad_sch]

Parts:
J2: Micro_SD_Card_Det_Hirose_DM3AT; microSD_HC_Hirose_DM3AT-SF-PEJM5
J3, J4: Conn_01x06_MountingPin; Hirose_FH12-6S-0.5SH_1x06-1MP_P0.50mm_Horizontal
R13, R14, R15, R16: 4.7k; R_0603_1608Metric

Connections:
+3V3: J3.1; also elsewhere on the board
/SDMMC_CLK: J3.4; also elsewhere on the board
/SDMMC_CS: J3.2; also elsewhere on the board
/SDMMC_MISO: J3.5; also elsewhere on the board
/SDMMC_MOSI: J3.3; also elsewhere on the board
GND: J3.6, J3.MP (MountPin); also elsewhere on the board
GND_SD: J2.6 (VSS), J2.11 (SHIELD), J4.1, J4.MP (MountPin)
unnamed: J2.5 (CLK), J4.3, R15.2
unnamed: J2.3 (CMD), J4.4, R14.2
unnamed: J2.7 (DAT0), J4.2, R16.2
unnamed: J2.2 (DAT3/CD), J4.5, R13.2
unnamed: J2.4 (VDD), J4.6, R13.1, R14.1, R15.1, R16.1

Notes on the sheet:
Placed near ESP32
Snappable PCB

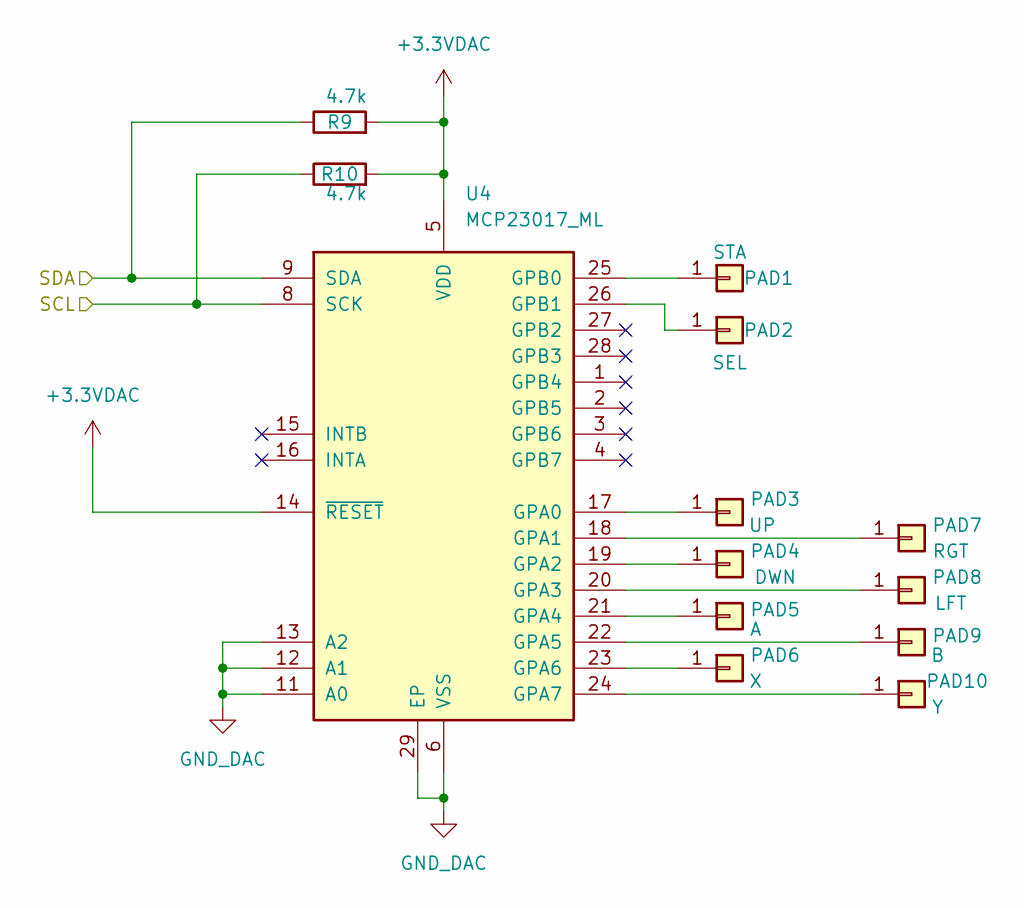
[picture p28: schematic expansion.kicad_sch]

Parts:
PAD1: STA; TestPoint_Pad_2.0x2.0mm
PAD2: SEL; TestPoint_Pad_2.0x2.0mm
PAD3: UP; TestPoint_Pad_2.0x2.0mm
PAD4: DWN; TestPoint_Pad_2.0x2.0mm
PAD5: A; TestPoint_Pad_2.0x2.0mm
PAD6: X; TestPoint_Pad_2.0x2.0mm
PAD7: RGT; TestPoint_Pad_2.0x2.0mm
PAD8: LFT; TestPoint_Pad_2.0x2.0mm
PAD9: B; TestPoint_Pad_2.0x2.0mm
PAD10: Y; TestPoint_Pad_2.0x2.0mm
R9, R10: 4.7k; R_0603_1608Metric
U4: MCP23017_ML; QFN-28-1EP_6x6mm_P0.65mm_EP4.25x4.25mm

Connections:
+3.3VDAC: R9.2, R10.2, U4.5 (VDD), U4.14 (~RESET); also elsewhere on the board
/Expansion port/SCL: R10.1, U4.8 (SCK); also elsewhere on the board
/Expansion port/SDA: R9.1, U4.9 (SDA); also elsewhere on the board
GND_DAC: U4.6 (VSS), U4.11 (A0), U4.12 (A1), U4.13 (A2), U4.29 (EP); also elsewhere on the board
unnamed: PAD1.1, U4.25 (GPB0)
unnamed: PAD2.1, U4.26 (GPB1)
unnamed: PAD3.1, U4.17 (GPA0)
unnamed: PAD4.1, U4.19 (GPA2)
unnamed: PAD5.1, U4.21 (GPA4)
unnamed: PAD6.1, U4.23 (GPA6)
unnamed: PAD7.1, U4.18 (GPA1)
unnamed: PAD8.1, U4.20 (GPA3)
unnamed: PAD9.1, U4.22 (GPA5)
unnamed: PAD10.1, U4.24 (GPA7)

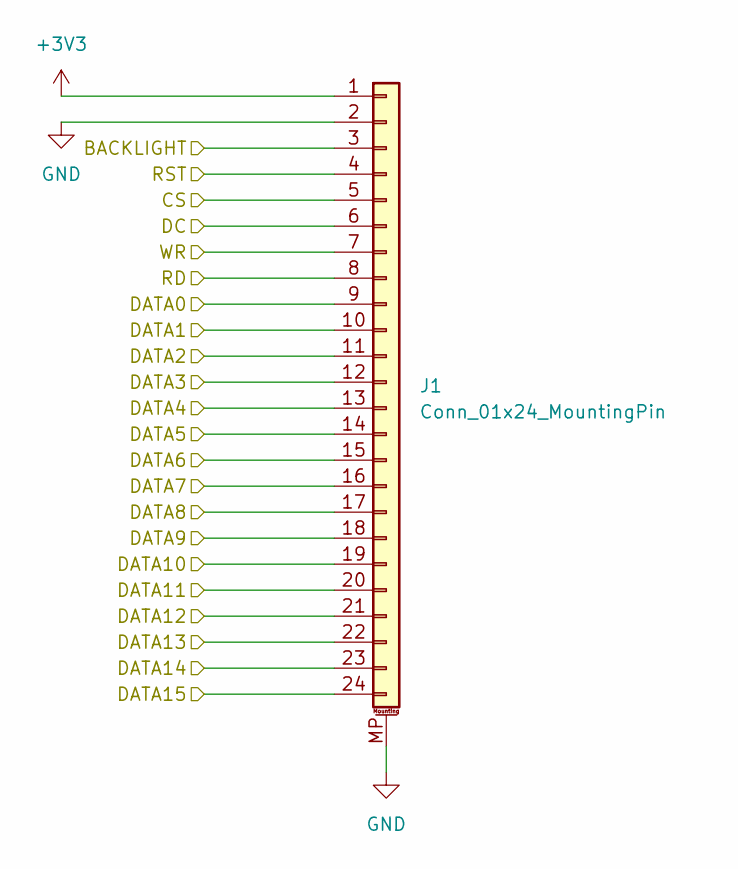
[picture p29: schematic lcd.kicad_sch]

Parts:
J1: Conn_01x24_MountingPin; Hirose_FH12-24S-0.5SH_1x24-1MP_P0.50mm_Horizontal

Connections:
+3V3: J1.1, J1.8; also elsewhere on the board
/BACKLIGHT: J1.3; also elsewhere on the board
/LCD_CS: J1.5; also elsewhere on the board
/LCD_D0: J1.9; also elsewhere on the board
/LCD_D1: J1.10; also elsewhere on the board
/LCD_D2: J1.11; also elsewhere on the board
/LCD_D3: J1.12; also elsewhere on the board
/LCD_D4: J1.13; also elsewhere on the board
/LCD_D5: J1.14; also elsewhere on the board
/LCD_D6: J1.15; also elsewhere on the board
/LCD_D7: J1.16; also elsewhere on the board
/LCD_D8: J1.17; also elsewhere on the board
/LCD_D9: J1.18; also elsewhere on the board
/LCD_D10: J1.19; also elsewhere on the board
/LCD_D11: J1.20; also elsewhere on the board
/LCD_D12: J1.21; also elsewhere on the board
/LCD_D13: J1.22; also elsewhere on the board
/LCD_D14: J1.23; also elsewhere on the board
/LCD_D15: J1.24; also elsewhere on the board
/LCD_DC: J1.6; also elsewhere on the board
/LCD_PCLK: J1.7; also elsewhere on the board
/LCD_RST: J1.4; also elsewhere on the board
GND: J1.2, J1.MP (MountPin); also elsewhere on the board

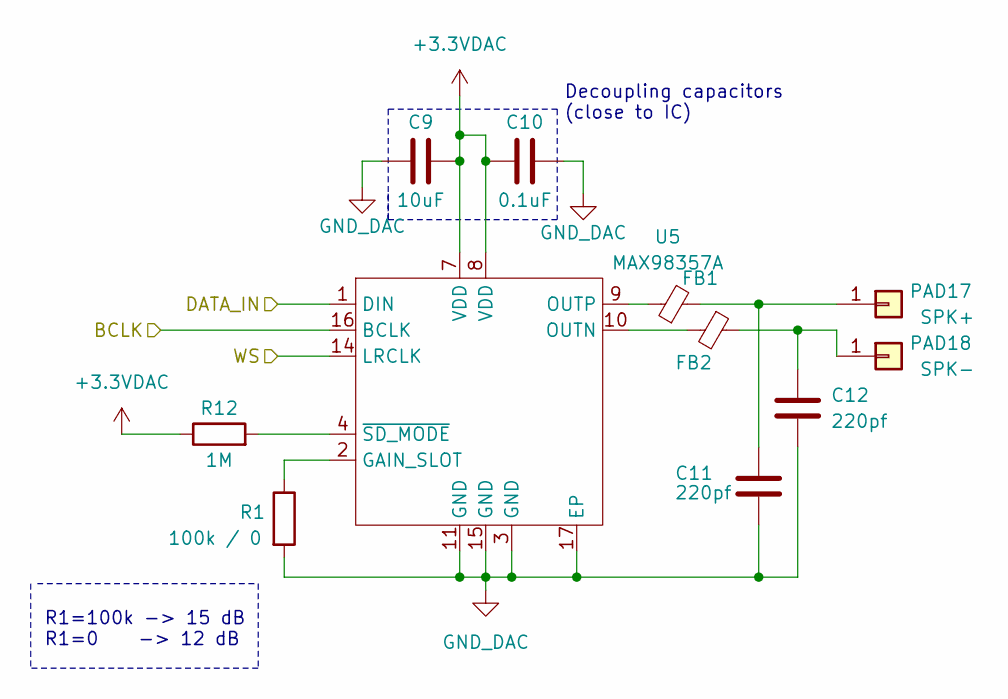
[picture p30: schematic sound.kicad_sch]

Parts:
C9: 10uF; C_0603_1608Metric
C10: 0.1uF; C_0603_1608Metric
C11, C12: 220pf; C_0603_1608Metric
FB1, FB2: FerriteBead_Small; L_0805_2012Metric
PAD17: SPK+; TestPoint_Pad_2.0x2.0mm
PAD18: SPK-; TestPoint_Pad_2.0x2.0mm
R1: 100k / 0; R_0805_2012Metric
R12: 1M; R_0805_2012Metric
U5: MAX98357A; TQFN-16-1EP_3x3mm_P0.5mm_EP1.23x1.23mm

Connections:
+3.3VDAC: C9.2, C10.1, R12.1, U5.7 (VDD), U5.8 (VDD); also elsewhere on the board
/I2S/BCLK: U5.16 (BCLK); also elsewhere on the board
/I2S/DATA_IN: U5.1 (DIN); also elsewhere on the board
/I2S/WS: U5.14 (LRCLK); also elsewhere on the board
GND_DAC: C9.1, C10.2, C11.2, C12.2, R1.2, U5.3 (GND), U5.11 (GND), U5.15 (GND), U5.17 (EP); also elsewhere on the board
unnamed: C11.1, FB1.2, PAD17.1
unnamed: C12.1, FB2.1, PAD18.1
unnamed: R1.1, U5.2 (GAIN_SLOT)
unnamed: FB2.2, U5.10 (OUTN)
unnamed: FB1.1, U5.9 (OUTP)
unnamed: R12.2, U5.4 (~SD_MODE)

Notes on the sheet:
Decoupling capacitors (close to IC)
R1=100k -> 15 dB R1=0 -> 12 dB

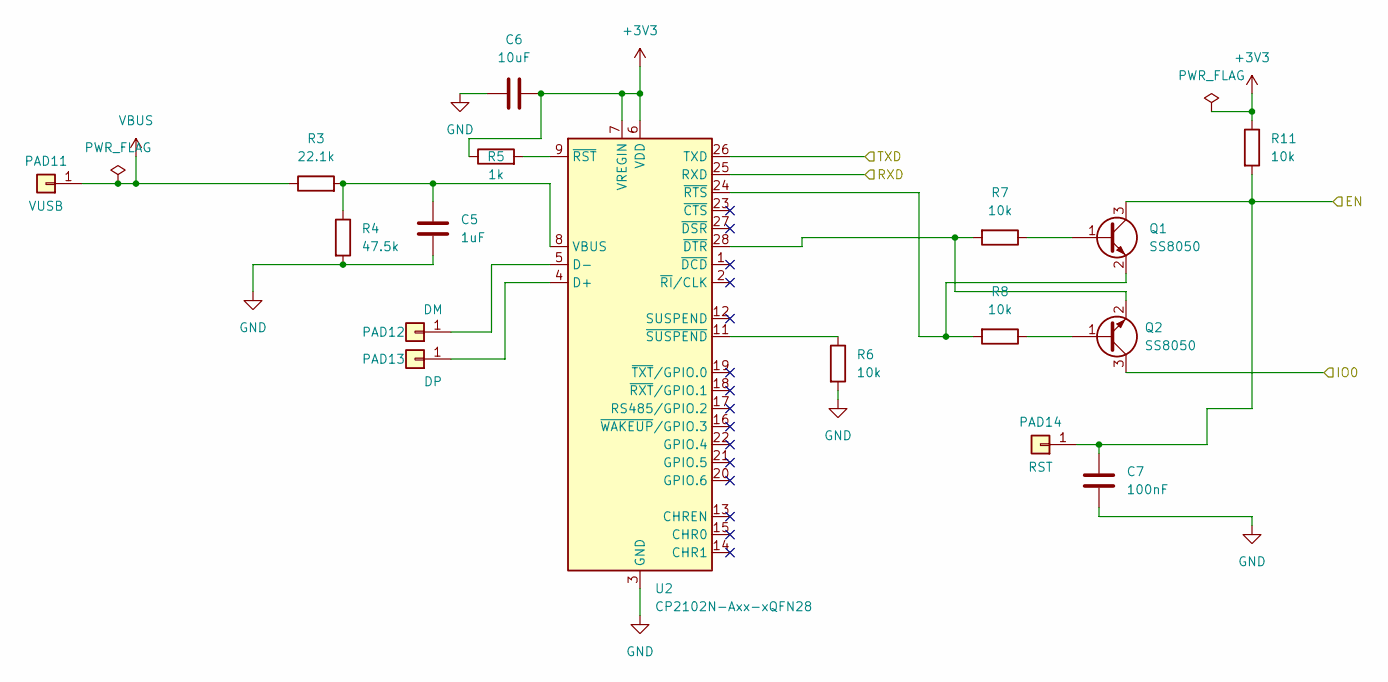
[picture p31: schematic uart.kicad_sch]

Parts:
C5: 1uF; C_0805_2012Metric
C6: 10uF; C_0805_2012Metric
C7: 100nF; C_0603_1608Metric
PAD11: VUSB; TestPoint_Pad_2.0x2.0mm
PAD12: DM; TestPoint_Pad_2.0x2.0mm
PAD13: DP; TestPoint_Pad_2.0x2.0mm
PAD14: RST; TestPoint_Pad_2.0x2.0mm
Q1, Q2: SS8050; SOT-23-3
R3: 22.1k; R_0603_1608Metric
R4: 47.5k; R_0603_1608Metric
R5: 1k; R_0603_1608Metric
R6, R7, R8, R11: 10k; R_0603_1608Metric
U2: CP2102N-Axx-xQFN28; QFN-28-1EP_5x5mm_P0.5mm_EP3.35x3.35mm

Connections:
+3V3: C6.2, R5.1, R11.1, U2.6 (VDD), U2.7 (VREGIN); also elsewhere on the board
/EN: C7.1, PAD14.1, Q1.3 (C), R11.2; also elsewhere on the board
/IO0: Q2.3 (C); also elsewhere on the board
/RXD: U2.26 (TXD); also elsewhere on the board
/TXD: U2.25 (RXD); also elsewhere on the board
GND: C5.2, C6.1, C7.2, R4.2, R6.2, U2.3 (GND), U2.29 (GND); also elsewhere on the board
unnamed: PAD12.1, U2.5 (D-)
unnamed: PAD13.1, U2.4 (D+)
unnamed: Q1.1 (B), R7.1
unnamed: Q1.2 (E), R8.2, U2.24 (~RTS)
unnamed: Q2.1 (B), R8.1
unnamed: Q2.2 (E), R7.2, U2.28 (~DTR)
unnamed: C5.1, R3.2, R4.1, U2.8 (VBUS)
unnamed: R5.2, U2.9 (~RST)
unnamed: R6.1, U2.11 (~SUSPEND)
VBUS: PAD11.1, R3.1

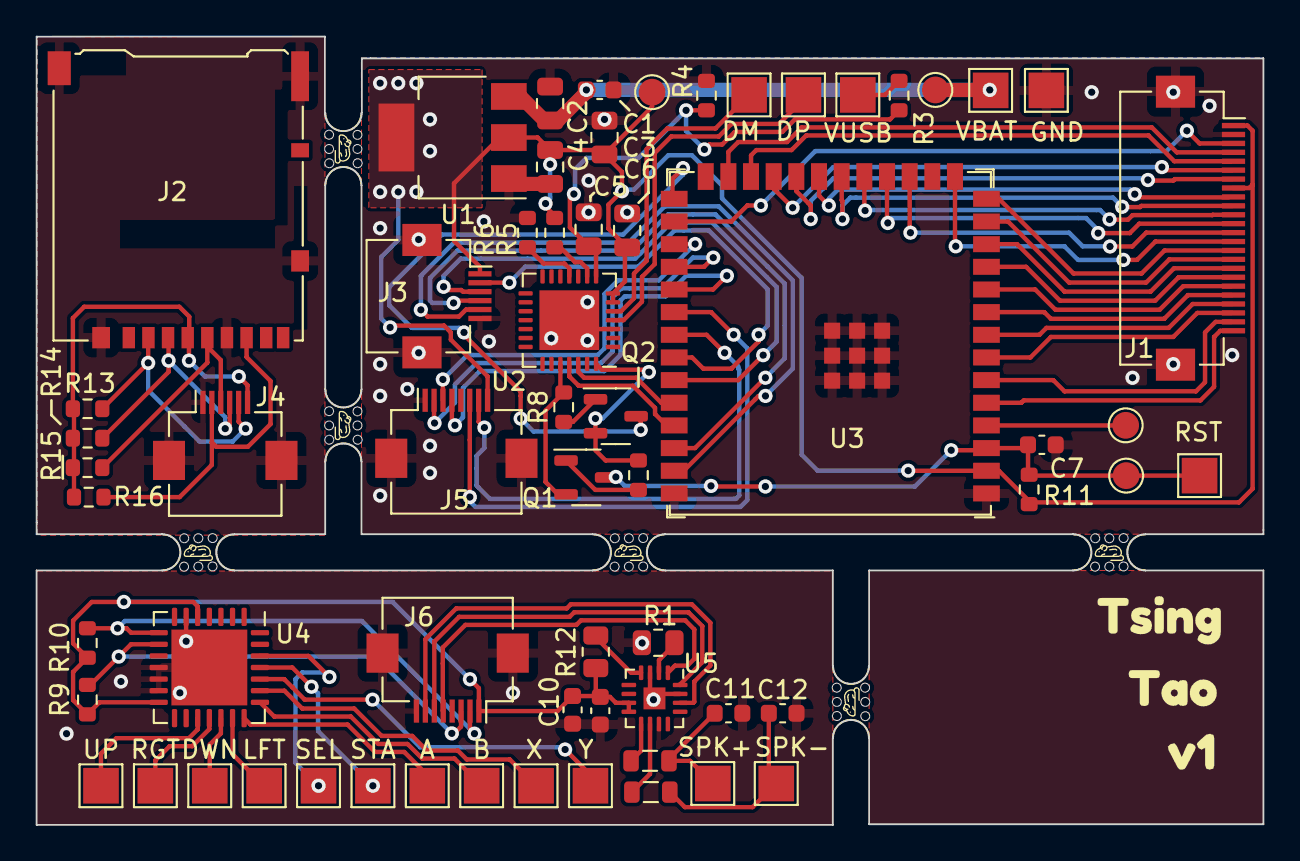
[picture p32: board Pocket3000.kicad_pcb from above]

Board: 2 copper layers, 68.8 x 44.2 mm, 72 parts (0 on the bottom side), 77 nets.

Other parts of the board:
kibuzzard-693B4E6F: G***; kibuzzard-693B4E6F
kibuzzard-693B4E49: G***; kibuzzard-693B4E49
kibuzzard-693B4E54: G***; kibuzzard-693B4E54
mouse-bite-2mm-4mm, mouse-bite-2mm-4mm#2, mouse-bite-2mm-4mm#3, mouse-bite-2mm-4mm#4, mouse-bite-2mm-4mm#5, mouse-bite-2mm-4mm#6: VAL**; mouse-bite-2mm-4mm

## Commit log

2025-12-11 First commit.
    [FH12-24S-0.5SH(55)--3DModel-STEP-1.STEP, Pocket3000.kicad_pcb, Pocket3000.kicad_sch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]
2025-12-18 Added PCB assembly and gerber zip file.
